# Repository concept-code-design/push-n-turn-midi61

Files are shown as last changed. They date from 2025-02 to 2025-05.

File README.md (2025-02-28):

# Push-n-Turn 61

Push-n-Turn 61 is a USB MIDI controller with 6 keyboard switches (RedDragon low profile), a rotary encoder and 7 RGB leds (WS8212).

The device sports a USB type-C connector and requires no device drivers on Mac or PC.

The keys can be configured (via MIDI messages, or the configurator) to produce notes, CC codes (momentary or toggle mode). The encoder produces 0..127 on a configurable CC channel. The encoder button produces 127/0 on a CC channel of choice.
Each switch has an RGB led that shows the state of the switch.
The device uses a modified midi library for CH55x devices made by mi:muz 

## Configuring the keys
Configuration of the keys can be done by sending midi codes to the device.
You can use python midiutil for this (https://github.com/sourcebox/midiutil).
The module listens to CC codes on channel 10 (0xBA on midiutil)

start configuration
0xBA, 0x64, 0x2A

end configuration and store data in EEprom
0xBA, 0x64, 0x2B

programming switches uses the following format
prefix (185) type+switch note/value
type is
	1: note mode
	2: CC momentary mode
	3: CC toggle mode
switch is 1..6
type and switch are combined into a number with first position for type, second for switch. So 12 is switch 2 in note mode, 35 is switch 5 in CC toggle mode
note/value is the note or CC code associated to the switch (C3 (middle C) is 60).

./midiutil.py -d 1 -w 185 11 60
will configure switch one to produce a C3 when pressed.

0xBA 0x64 0x2C
produces device type 0xBA 0x64 0x61 in [61, 31, 40, 51, F4] for 6key+1rot, you get the idea

0xBA 0x64 0x2D
returns the firmware revision: 0xBA, 0x64, 0x10 for instance for rev 1.0

## Links & References

* [mi:muz:ch55x Tiny USB MIDI Library for Ch55xduino](https://github.com/mimuz/mimuz-ch55x)
* []()

# License

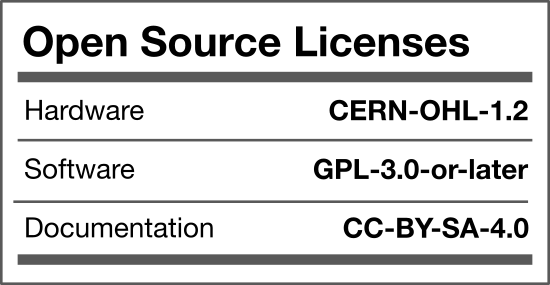
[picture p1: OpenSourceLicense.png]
OpenSourceLicense


Concept & Code invests time and resources providing this open source design, please support them and open-source hardware by purchasing products from Etsy or Tindie!

Designed by Ronald Leenes.

Firmware released under an GNU AGPL v3.0 license. See the LICENSE file for more information.

Hardware released under an CERN Open Hardware Licence v1.2. See the LICENSE_HARDWARE file for more information.

February 2025

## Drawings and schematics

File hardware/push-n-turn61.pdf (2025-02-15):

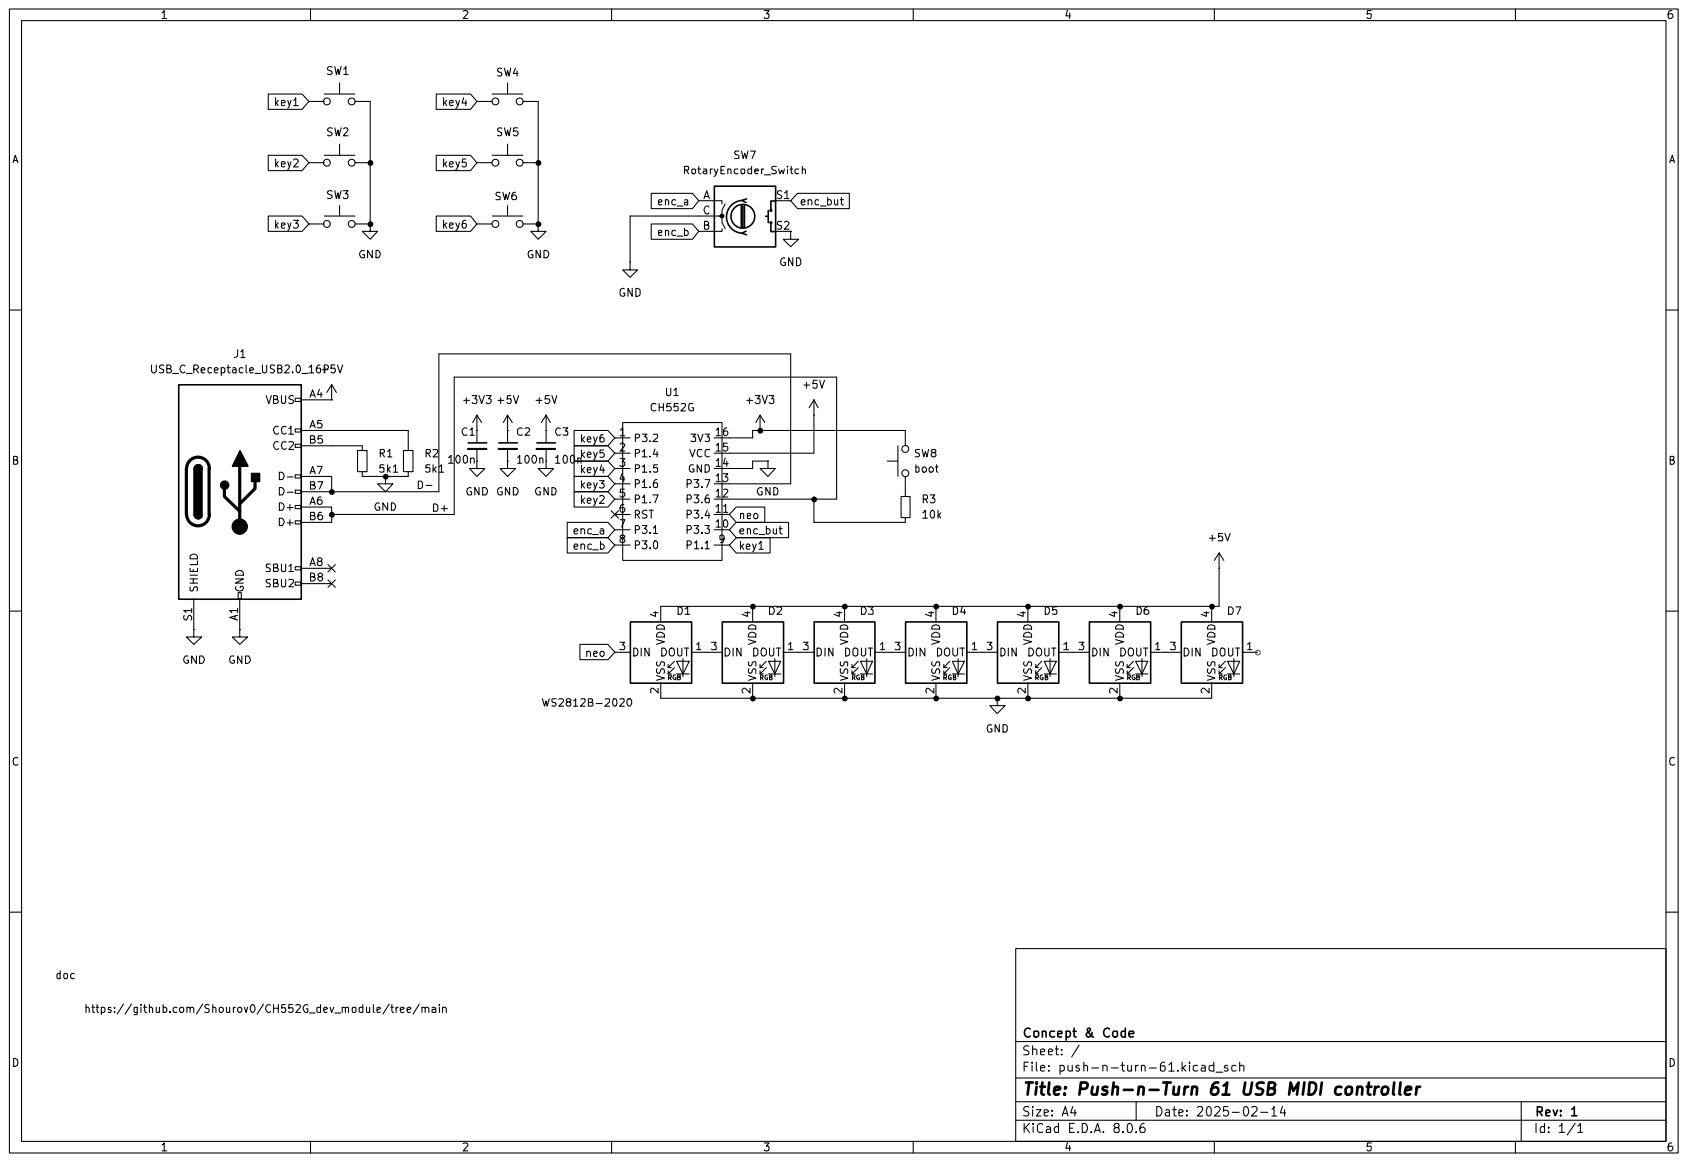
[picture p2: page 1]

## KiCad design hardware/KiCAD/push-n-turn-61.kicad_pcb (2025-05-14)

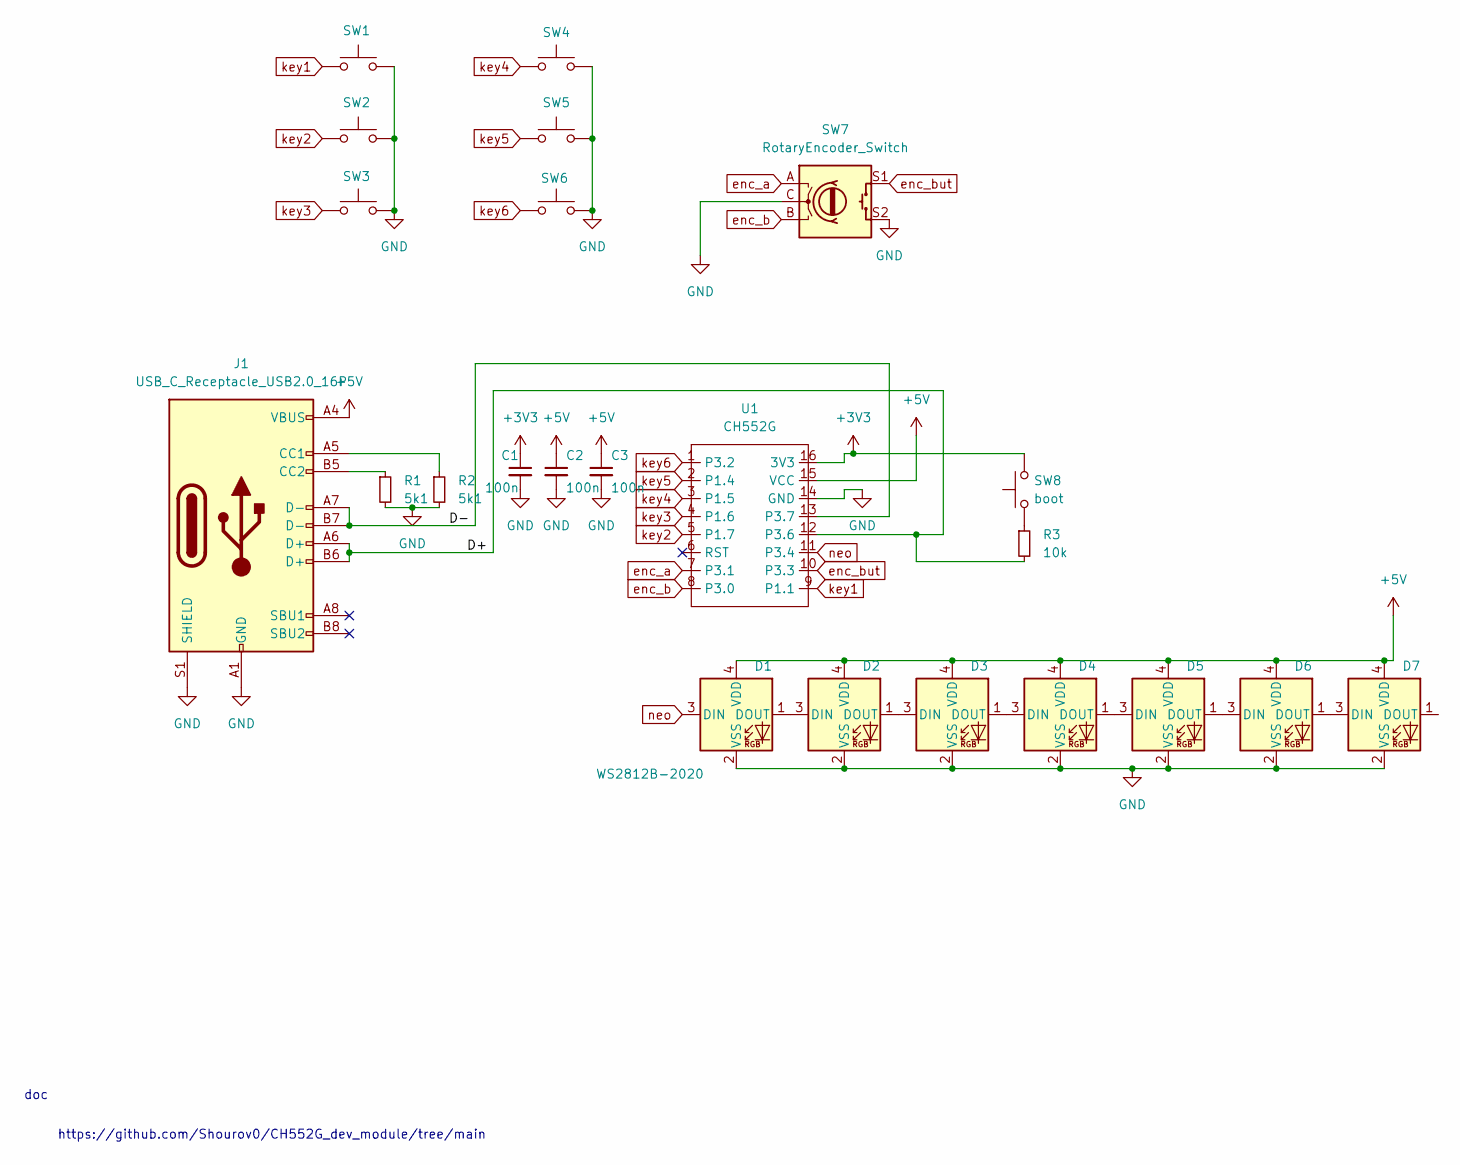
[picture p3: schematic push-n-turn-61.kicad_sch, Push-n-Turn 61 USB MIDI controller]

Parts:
C1, C2, C3: 100n; C_0805_2012Metric
D1, D2, D3, D4, D5, D6, D7: WS2812B-2020; LED_WS2812B-2020_PLCC4_2.0x2.0mm
J1: USB_C_Receptacle_USB2.0_16P; USB_C_Receptacle_GCT_USB4105-xx-A_16P_TopMnt_Horizontal
R1, R2: 5k1; R_0805_2012Metric
R3: 10k; R_0805_2012Metric
SW1: key1; SW_RedDragon5.5m_Ali_1.00u
SW2: key2; SW_RedDragon5.5m_Ali_1.00u
SW3, SW6: key3; SW_RedDragon5.5m_Ali_1.00u
SW4: key4; SW_RedDragon5.5m_Ali_1.00u
SW5: key5; SW_RedDragon5.5m_Ali_1.00u
SW7: RotaryEncoder_Switch; RotaryEncoder_Alps_EC11E_Vertical_H20mm
SW8: boot; SW_Push_SPST_NO_Alps_SKRK
U1: CH552G; SOP-16_4.4x10.4mm_P1.27mm

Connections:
+3V3: C1.1, SW8.2, U1.16 (3V3)
+5V: C2.1, C3.1, D1.4 (VDD), D2.4 (VDD), D3.4 (VDD), D4.4 (VDD), D5.4 (VDD), D6.4 (VDD), D7.4 (VDD), J1.A4 (VBUS), J1.A9 (VBUS), J1.B4 (VBUS), J1.B9 (VBUS), U1.15 (VCC)
/D+: J1.A6 (D+), J1.B6 (D+), R3.2, U1.12 (P3.6)
/D-: J1.A7 (D-), J1.B7 (D-), U1.13 (P3.7)
GND: C1.2, C2.2, C3.2, D1.2 (VSS), D2.2 (VSS), D3.2 (VSS), D4.2 (VSS), D5.2 (VSS), D6.2 (VSS), D7.2 (VSS), J1.A1 (GND), J1.A12 (GND), J1.B1 (GND), J1.B12 (GND), J1.S1 (SHIELD), R1.2, R2.2, SW1.2, SW2.2, SW3.2, SW4.2, SW5.2, SW6.2, SW7.C, SW7.S2, U1.14 (GND)
unnamed: D1.1 (DOUT), D2.3 (DIN)
unnamed: D2.1 (DOUT), D3.3 (DIN)
unnamed: D3.1 (DOUT), D4.3 (DIN)
unnamed: D4.1 (DOUT), D5.3 (DIN)
unnamed: D5.1 (DOUT), D6.3 (DIN)
unnamed: D6.1 (DOUT), D7.3 (DIN)
unnamed: J1.A5 (CC1), R2.1
unnamed: J1.B5 (CC2), R1.1
unnamed: R3.1, SW8.1
enc_a: SW7.A, U1.7 (P3.1)
enc_b: SW7.B, U1.8 (P3.0)
enc_but: SW7.S1, U1.10 (P3.3)
key1: SW1.1, U1.9 (P1.1)
key2: SW2.1, U1.5 (P1.7)
key3: SW3.1, U1.4 (P1.6)
key4: SW4.1, U1.3 (P1.5)
key5: SW5.1, U1.2 (P1.4)
key6: SW6.1, U1.1 (P3.2)
neo: D1.3 (DIN), U1.11 (P3.4)

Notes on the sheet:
https://github.com/Shourov0/CH552G_dev_module/tree/main
doc

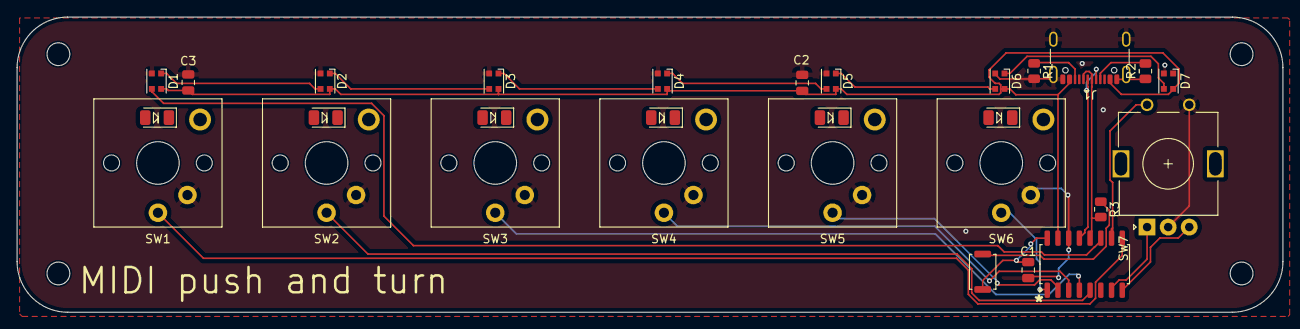
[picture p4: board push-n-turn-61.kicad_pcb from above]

Board: 2 copper layers, 150.1 x 35.0 mm, 27 parts (0 on the bottom side), 24 nets.

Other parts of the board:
h1, h1#2, h1#3, h1#4: MountingHole_2.7mm_M2.5_ISO14580

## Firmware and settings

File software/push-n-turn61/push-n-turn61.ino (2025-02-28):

// ===================================================================================
// Project:   Push-n-Turn (31, 41, 61)
// Version:   v1.0
// Year:      2025
// Author:    Ronald Leenes
// Github:    https://github.com/concept-code-design
// License:   GNU AGPL v3.0 license
// ===================================================================================
//
// Description:
// ------------
// Firmware for the various Push-n-Turn midi controllers building on mimuz-ch55x midi library for CH55x chips
//
// References:
// -----------
// - D.F.Mac. : https://github.com/mimuz/mimuz-ch55x
// - WCH Nanjing Qinheng Microelectronics: http://wch.cn

#include "config.h"
#include "vars.h"
#include "push-n-turn.h"
#include "colors.h"
#include "mimuz-ch55x.h"
#include <WS2812.h>

#ifndef USER_USB_RAM
#error "This sketch needs to be compiled with a USER USB setting"
#endif

void setup(){
 readEEPROM();
  init_PINS();
  if (NUM_ENCODERS > 0) init_ENCODER();

  init_NEO();

  check_PROGBOOT_REQUEST();
  USBInit();
  setHdlCtlChange(onCTLChange);
}

void loop() {
  switchUpdate();
  if (NUM_ENCODERS > 0) encoderUpdate();
  processMidiMessage();
  USBSerial_flush();
}

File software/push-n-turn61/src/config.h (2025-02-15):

// ===================================================================================
// User Configurations for CH552G USB MacroPad Plus
// ===================================================================================

#pragma once
/*
// Pin definitions
#define PIN_NEO             P16         // pin connected to NeoPixel
#define PIN_KEY1            P17         // pin connected to key 1
#define PIN_KEY2            P31         // pin connected to key 2
#define PIN_KEY3            P30         // pin connected to key 3
#define PIN_KEY4            P15         // pin connected to key 4
#define PIN_KEY5            P14         // pin connected to key 5
#define PIN_KEY6            P32         // pin connected to key 6
#define PIN_ENC_A           P34         // pin connected to rotary encoder A
#define PIN_ENC_B           P33         // pin connected to rotary encoder B
#define PIN_ENC_SW          P11         // pin connected to rotary encoder switch

*/
// NeoPixel configuration
#define NEO_COUNT           3          // number of pixels in the string
#define NEO_RGB                         // type of pixel: NEO_GRB or NEO_RGB


// USB device descriptor
#define USB_VENDOR_ID       0x1189      // VID
#define USB_PRODUCT_ID      0x8890      // PID
#define USB_DEVICE_VERSION  0x0100      // v1.0 (BCD-format)

// USB configuration descriptor
#define USB_MAX_POWER_mA    150         // max power in mA 

// USB descriptor strings
#define MANUFACTURER_STR    'w','a','g','i','m','i','n','a','t','o','r'
#define PRODUCT_STR         'M','a','c','r','o','P','a','d'
#define SERIAL_STR          'C','H','5','5','2','x','H','I','D'
#define INTERFACE_STR       'H','I','D','-','K','e','y','b','o','a','r','d'

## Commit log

2025-03-23 small fixes
    small fixes
    [midi.ino, util.ino, vars.h]
2025-05-14 added KiCad files
    [push-n-turn-61.kicad_pcb, push-n-turn-61.kicad_sch]
